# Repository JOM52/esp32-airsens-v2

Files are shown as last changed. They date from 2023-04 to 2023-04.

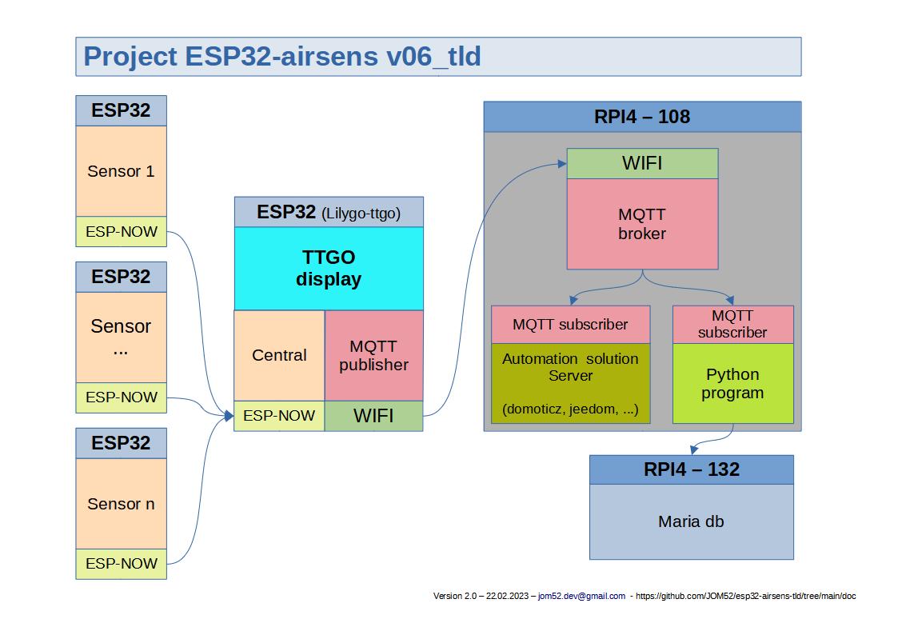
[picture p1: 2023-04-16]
doc/Schéma de principe.jpg

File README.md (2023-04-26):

# Projet : esp32-airsens 

Version 2

**esp32-airsens** est un projet de domotique qui consiste à créer des capteurs intelligents et connectés pour surveiller l'environnement. Ces capteurs sont basés sur le processeur ESP32 et le langage Micropython. Ils peuvent mesurer différents paramètres tels que la température, l'humidité, la pression atmosphérique et le niveau de charge de batterie. Ils envoient ensuite ces données à une centrale via un réseau sans fil. La centrale est un système Liligo TTGO qui reçoit les données des capteurs, les publie sur un broker MQTT et les affiche sur un écran. L'écran permet de visualiser les informations pertinentes pour chaque capteur.

La version 2 du projet introduit un nouveau concept pour la structure des données qui n'est pas compatible avec la version 1. Ce concept permet de simplifier la communication entre les capteurs et la centrale, ainsi que de gérer plus facilement les différents types de capteurs.

## Schéma de principe
https://github.com/JOM52/esp32-airsens-v2/blob/main/doc/Sch%C3%A9ma%20de%20principe.jpg

## Elément capteur:

La version 1.06_tld du hardware fonctionne bien et ne nécessite pas de modification.

Pour réduire la consommation d'énergie, cette version hard ne contient que l'essentiel pour faire fonctionner le capteur. La configuration se fait par une interface FTDI (USB to UART) qui se branche au besoin et les batteries se rechargent à part.

Dans l'exemple ci-après, le capteur est un BME 280 qui permet la mesure de la température, du taux d'humidité et de la pression atmosphérique.

https://github.com/JOM52/esp32-airsens-v2/blob/main/schema/Schema.pdf

On peut aussi utiliser des capteurs hdc1080 qui mesurent seulement la température et l'humidité relative.

### Hardware

Le hardware ESP32 est un microcontrôleur qui intègre des fonctionnalités de Wi-Fi et de Bluetooth, ainsi que des modules de gestion de l'alimentation, des filtres et des amplificateurs. Il peut se connecter à différents types de capteurs I2C, un protocole de communication série synchrone. 

### Software

Ce projet implémente les drivers pour les capteurs de type BME280, BME680 et HDV1080. Ces capteurs permettent de mesurer différentes grandeurs liées au climat ou à l'environnement. Dans la version 2 du projet, on peut choisir le type et le nombre de capteurs à utiliser dans le fichier de configuration. Toutefois, il faut tenir compte de l'impact sur la consommation d'énergie et la durée de vie de la batterie. Avec une batterie Li-Ion de 2Ah (type 18650), on peut, avec un seul capteur,  réaliser une mesure toutes les 5 minutes pendant environ un an.

#### Fichier de configuration du capteur

Le fichier de configuration permet de personnaliser le fonctionnement d'un capteur sans avoir à modifier le code source. Il contient des lignes de code en Micropython qui assignent des valeurs à des variables globales. Ces variables sont ensuite utilisées par le programme principal pour paramétrer les différents éléments du système. Le fichier de configuration n'a pas besoin d'une structure particulière, mais il peut être organisé en sections pour faciliter la lecture et la compréhension.

Le code ci-après permet de configurer un capteur connecté à un ESP32 qui utilise le protocole ESP-now pour envoyer des données à un proxy. Le capteur peut être de type hdc1080, bme280 ou bme680 et mesure la température, l'humidité, la pression, le gaz et l'altitude selon le cas. Le capteur est alimenté par une batterie et entre en mode deepsleep entre chaque acquisition pour économiser de l'énergie. La tension de la batterie est mesurée par un pont diviseur de tension. Le code utilise les constantes définies au début du fichier pour paramétrer les différents éléments du système. Par exemple, SENSOR_LOCATION indique le nom du capteur, T_DEEPSLEEP_MS indique la durée du mode deepsleep en millisecondes, SENSORS indique les types de capteurs disponibles et leurs mesures associées, ON_BATTERY indique si le capteur est alimenté par une batterie ou non, etc. Le code utilise également la variable PROXY_MAC_ADRESS pour indiquer l'adresse MAC du proxy auquel il envoie les données via 

Le code ci-dessous montre un exemple de fichier de configuration pour ce système:

```
# acquisitions
SENSOR_LOCATION = 'domo_2' 
T_DEEPSLEEP_MS = 300000

# sensor
SENSORS = {
    'hdc1080':['temp', 'hum'],
    'bme280':['temp', 'hum', 'pres'],
    'bme680':['temp', 'hum', 'pres', 'gas', 'alt']
    }
    
# power supply
ON_BATTERY = True
UBAT_100 = 4.2
UBAT_0 = 3.1

# I2C hardware config
BME_SDA_PIN = 21
BME_SCL_PIN = 22

# analog voltage measurement
R1 = 977000 # first divider bridge resistor
R2 = 312000 # second divider bridge resistor
DIV = R2 / (R1 + R2)  
ADC1_PIN = 35 # Measure of analog voltage (ex: battery voltage following)

#averaging of measurements
AVERAGING_BAT = 1
AVERAGING_BME = 1

# ESP-now
PROXY_MAC_ADRESS = b'<a\x05\rg\xcc'
# PROXY_MAC_ADRESS = b'<a\x05\x0c\xe7('
```

### Messages

Les valeurs mesurées pour chaque grandeur sont regroupées et transmises au broker MQTT dans un seul message. Le format de principe du message est le suivant:

`msg = (topic, location, grandeur 1, grandeur 2, .... , grandeur n, bat, rssi)`

Les grandeurs mesurées sont dépendantes des possibilités du capteur par exemple:

- HDC1080 : température, humidité
- BME280  : température, humidité, pression
- BME680  : température, humidité, pression, qualité de l'air

Les valeurs transmises à MQTT sont fonction de la configuration définie dans le fichier _conf du capteur.

#### Principe du logiciel capteur

Pour économiser l'énergie consommée, le capteur est placé en ***deepsleep*** entre chaque mesure. Le temps de sommeil est défini dans le fichier de configuration, en principe 5 minutes. Lors d'un éveil, le capteur lit le fichier de configuration, initialise les constantes, charge les librairies nécessaire, initialise le capteur, fait la mesure, mesure l'état de la batterie, transmets les valeurs à la centrale puis se met en ***deepsleep***

## Centrale

### Software

La centrale est le cœur du système de domotique. Elle a plusieurs fonctions :

- Elle reçoit et traite les messages valides envoyés par les capteurs sans fil.
- Elle adapte les messages au format de l'application de domotique choisie (domoticz, jeedom, ...).
- Elle transmet les valeurs de mesure à MQTT, un protocole de communication qui permet de diffuser les informations aux abonnés.
- Elle affiche différentes informations sur un écran couleur, comme les mesures et l'état des batteries des capteurs.

Les messages reçus ne sont pas confirmés au capteur. Cela signifie que si la centrale n'est pas disponible au moment où le capteur envoie un nouveau message, celui-ci est perdu. En principe cela ne pose pas de problème pour les mesures de grandeurs physiques qui varient peu dans le temps.

La centrale accepte tous les messages qui ont une structure correcte et qui proviennent d'un capteur dont elle connaît l'adresse MAC. Si le capteur est déjà enregistré dans le fichier de configuration et dans la mémoire programme, les nouvelles valeurs remplacent les anciennes. Sinon, le capteur est automatiquement reconnu et ajouté au fichier de configuration et à la mémoire programme.

La centrale dispose de deux boutons sur la version matérielle des Lilygo-ttgo qui permettent de sélectionner les différents affichages programmés. le choix se fait lorsque aucun bouton n'est pressé pendant 1 seconde.

Pour transmettre les mesures à MQTT, la centrale se connecte au réseau WIFI. Les valeurs de mesure sont formatées selon les besoins de l'application de domotique choisie puis envoyées au broker MQTT qui les publie aux abonnés.

### Fichier de configuration de la centrale

Le fichier de configuration est un fichier standard Micropython. 

```
#!/usr/bin/env python3
# -*- coding: utf-8 -*-
"""
file: airsens_central_v2.py 
author: jom52
email: jom52.dev@gmail.com
github: https://github.com/JOM52/esp32-airsens-v2

v0.4.0 : 05.02.2023 --> first prototype
v0.4.1 : 05.03.2023 --> small changes Venezia
v2.0.0 : 11.04.2023 --> adapté pour la version 2
"""
from ubinascii import hexlify
from machine import unique_id

#SYSTEM
WAIT_TIME_ON_RESET = 300 # seconds to wait before the machine reset in case of error

# MQTT
BROKER_IP = '192.168.1.108'
TOPIC = 'airsens_domoticz'
BROKER_CLIENT_ID = hexlify(unique_id())

# TTGO
BUTTON_MODE_PIN = 35
BUTTON_PAGE_PIN = 0
DEFAULT_MODE = 0 # Mode auto
DEFAULT_ROW_ON_SCREEN = 5 # given by the display hardware and the font size
CHOICE_TIMER_MS = 1000 # milli seconds
REFRESH_SCREEN_TIMER_MS = 10000 # mode auto: display next location each ... milli seconds
BUTTON_DEBOUNCE_TIMER_MS = 10 # milli seconds

# WIFI
WIFI_WAN = 'jmb-home'
WIFI_PW = 'lu-mba01'

# BATTERY
BAT_MAX = 4.2 # 100%
BAT_MIN = 3.2 # 0%
BAT_OK = 3.4 # si ubat plus grand -> ok
BAT_LOW = 3.3 # si ubat plus petit -> alarm
BAT_PENTE = (100-0)/(BAT_MAX-BAT_MIN)
BAT_OFFSET = 100 - BAT_PENTE * BAT_MAX
print('% = ' + str(BAT_PENTE) + ' + ' + str(BAT_OFFSET))
```

#### Code de la centrale évolution

*Dans une prochaine version il est prévu de modifier le programme pour:*

- *introduire un processus d'identification et d'enregistrement des capteurs par la centrale. Ainsi seuls des capteurs reconnus, validés et enregistrés seront autorisés à transmettre des mesures à la centrale.*
- *de crypter les message pour empêcher que les messages soient lus par des entités non autorisées.*

### Hardware

La centrale utilise un circuit Lilygo-ttgo qui comprend le processeur, une interface USB, un affichage de 135x240 pixels et deux boutons. Dans la version actuelle, ce circuit est utilisé tel quel. Les boutons sont utilisés comme suit:

- bouton 1 --> next **Mode**

- bouton 2 --> next **Page**

  le choix se fait lorsque aucun bouton n'est pressé pendant 1 seconde

### Connection réseau attribution des canaux

Désactivez l'attribution automatique des canaux sur votre routeur Wi-Fi : si le routeur Wi-Fi de votre réseau Wi-Fi est configuré pour attribuer automatiquement le canal Wi-Fi, il peut changer le canal du réseau s'il détecte des interférences provenant d'autres routeurs Wi-Fi. Lorsque cela se produit, les appareils ESP connectés au réseau Wi-Fi changeront également de canal pour correspondre au routeur, mais les autres appareils ESPNow uniquement resteront sur le canal précédent et la communication sera perdue. Pour atténuer cela, configurez votre routeur Wi-Fi pour qu'il utilise un canal Wi-Fi fixe ou configurez vos appareils pour analyser à nouveau les canaux Wi-Fi s'ils ne parviennent pas à trouver leurs homologues attendus sur le canal actuel.

Il faut configurer le sensor pour utiliser le même canal (channel) que le router wifi

## MQTT mosquitto

Le logiciel MQTT fonctionne comme un éditeur (broker). Il est à l'écoute des auteur (publishers) qui publient des données et les diffuse auprès des abonnés (subscribers).

MQTT est installé comme un service sur un Raspberry PI. Il reçoit les informations transmises par les auteurs qui publient les données (les capteurs) et les rediffuse vers tous les abonnés sans aucun contrôle de validité. Son rôle se limite à faire transiter les données depuis les auteurs vers les abonnés. La responsabilité de la validation et du contrôle des données est laissé à la centrale.

Pour recevoir les données depuis le broker il suffit souscrire au broker sur le TOPIC concerné.

*description de l'installation et de la configuration de MQTT à placer ici* 

## Programme python airsens_mqtt

C'est un programme Python qui s'abonne à des topics MQTT pour les capteurs dont les données doivent être enregistrées dans une base de données. Ce programme est installé comme un service sur le raspberry PI. 

Il consulte le fichier de configuration de la centrale pour connaitre les mac-adress des capteurs reconnus par la centrale.

Il reçoit les données depuis MQTT, vérifie que le capteur est reconnu et, si oui, les enregistre dans la base de données airsens sur MariaDB (anciennement MySql) sur le Raspberry PI .

Ce programme se charge également d'alarmer l'utilisateur (par un mail, un WhatsApp ou autre) lorsque l'accumulateur d'un capteur doit être rechargé. 

*description de l'installation d'un service sur RPI à placer ici*

## Programme de domotique

Les mesures des capteurs peuvent être transmises à un logiciel de domotique (domoticz, jeedom, ...) pour être représentés graphiquement ou intervenir dans différentes alarmes. 

La gestion des messages à destination des logiciels de domotique se font pour chaque logiciel  (domoticz, jeedom, ...) dans une classe spécifique.

Pour Domoticz, le format des messages est le suivant:

 {  "**command**": "udevice",  "**idx**" : 7,  "**nvalue**" : 0,  "**svalue**" : "90;2975.00", "**parse**": false } avec:

- **command**: udevice pour un capteur
- **idx**: index du capteur dans domoticz
- **nvalue**: sans importance pour un capteur
- **svalue**: valeurs mesurées p.ex. température; humidité; pression, ...

plus de détails: https://piandmore.wordpress.com/2019/02/04/mqtt-out-for-domoticz/

## Corrections à apporter

- [ ] **Identification unique des capteurs**
  - [ ] Compléter le topic par le type de capteur et un id unique pour pouvoir assurer de différentier chaque capteur donc 
    le TOPIC sera constitué comme suit: SENSOR_LOCATION / SENSOR_TYPE / SENSOR_ID 
  - [ ] Adapter le programme airsens_v2_jeedom.py
  - [ ] Adapter la table airsens_v2 dans la base de données airsens sur le RPI 139 
- [ ] **Perte de connexion en cas de coupure réseau**
  - [ ] En cas de coupure réseau, le central se perd et ne redémarre pas automatiquement. 
- [ ] **Sensor**
  - [ ] Analyser si la possibilité d'avoir plusieurs sensors sur un seul capteur à du sens et si non supprimer le code correspondant
  - [ ] Prévoir de désactiver les messages pour le suivi si le sensor est sur batterie (ON_BATTERY = False)
- [ ] **Central**
  - [ ] Analyser pourquoi le programme se plante et ne redémarre pas en cas de coupure réseau 
- [ ] **Capteur**
  - [ ] Modifier la valeur du condensateur (C3) (10uF ?) pour que le reset se fasse à l'enclenchement du sensor
  - [ ] Etudier si l'implémentation du FTDI sur le capteur à du sens ou s'il rester avec un FTDI externe

Ce thème fera objet d'un futur projet.

## GITHUB

Ce projet est maintenu dans GitHub, avec une licence GPL. Il est accessible par le lien 
https://github.com/JOM52/esp32-airsens-v2

Pravidondaz avril 2023

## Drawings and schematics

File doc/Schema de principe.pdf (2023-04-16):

# ESP32 RPI4 – 108

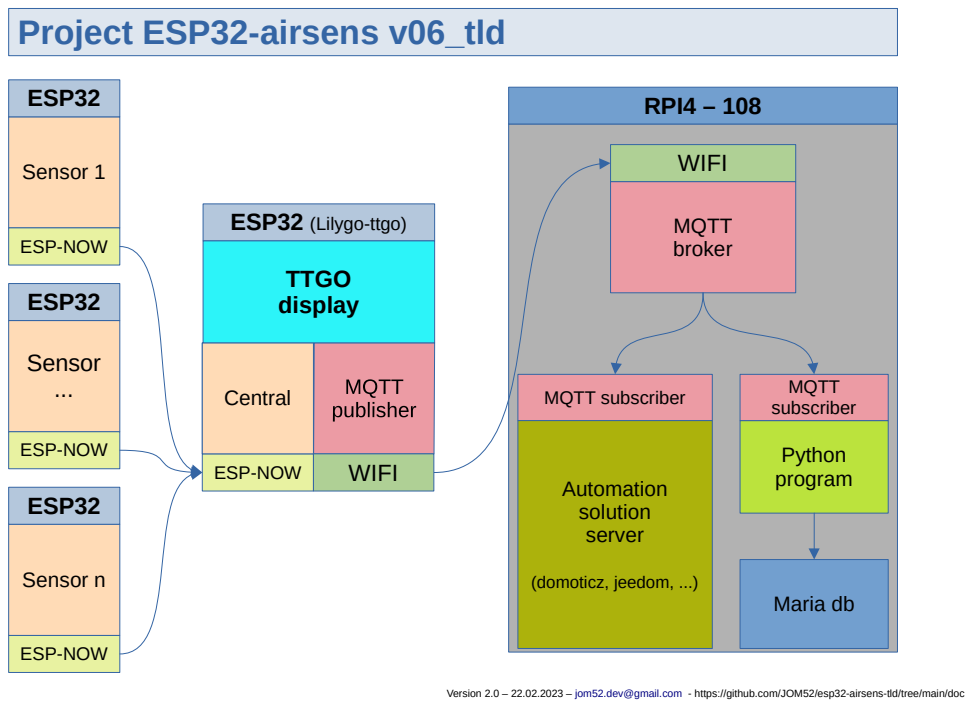
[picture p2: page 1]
Sensor 1; ESP-NOW; Sensor ...; ESP32; Sensor n; ESP32 (Lilygo-ttgo); MQTT broker; MQTT subscriber; Python program; Maria db; WIFI; Automation solution server; (domoticz, jeedom, ...); Project ESP32-airsens v06_tld; MQTT subscriber Central; TTGO display

Central

ESP-NOW | WIFI

Version 2.0 – 22.02.2023 – jom52.dev@gmail.com - https://github.com/JOM52/esp32-airsens-tld/tree/main/doc

# ESP32

# RPI4 – 108

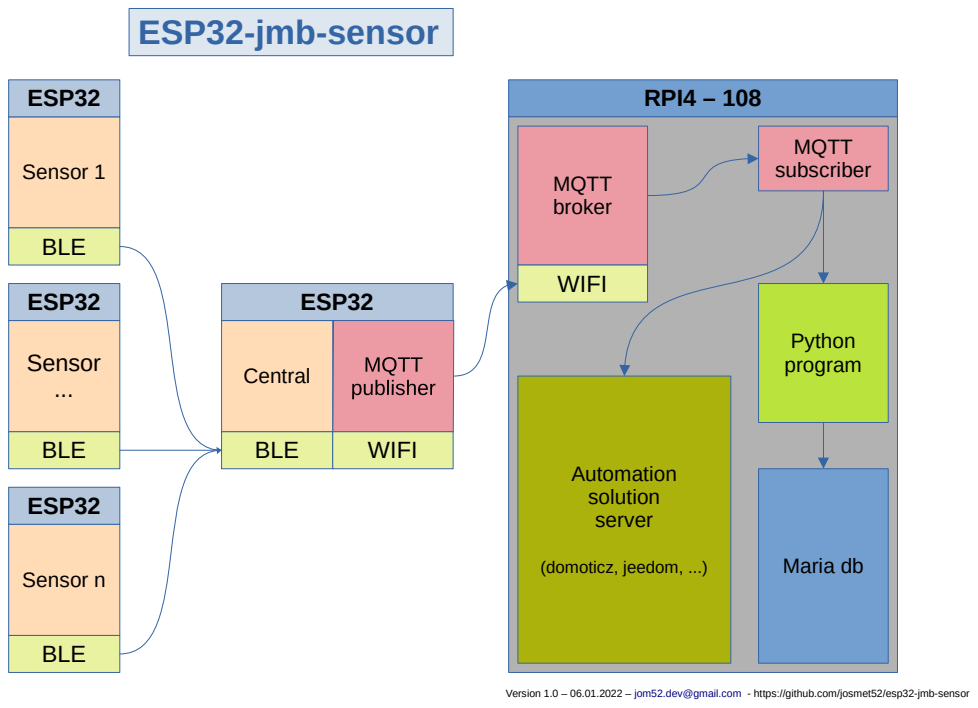
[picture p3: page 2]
Sensor 1; BLE; Sensor ...; ESP32; Sensor n; Central; MQTT broker; MQTT subscriber; Python program; Maria db; WIFI; Automation solution server; (domoticz, jeedom, ...); ESP32-jmb-sensor

Version 1.0 – 06.01.2022 – jom52.dev@gmail.com - https://github.com/josmet52/esp32-jmb-sensor

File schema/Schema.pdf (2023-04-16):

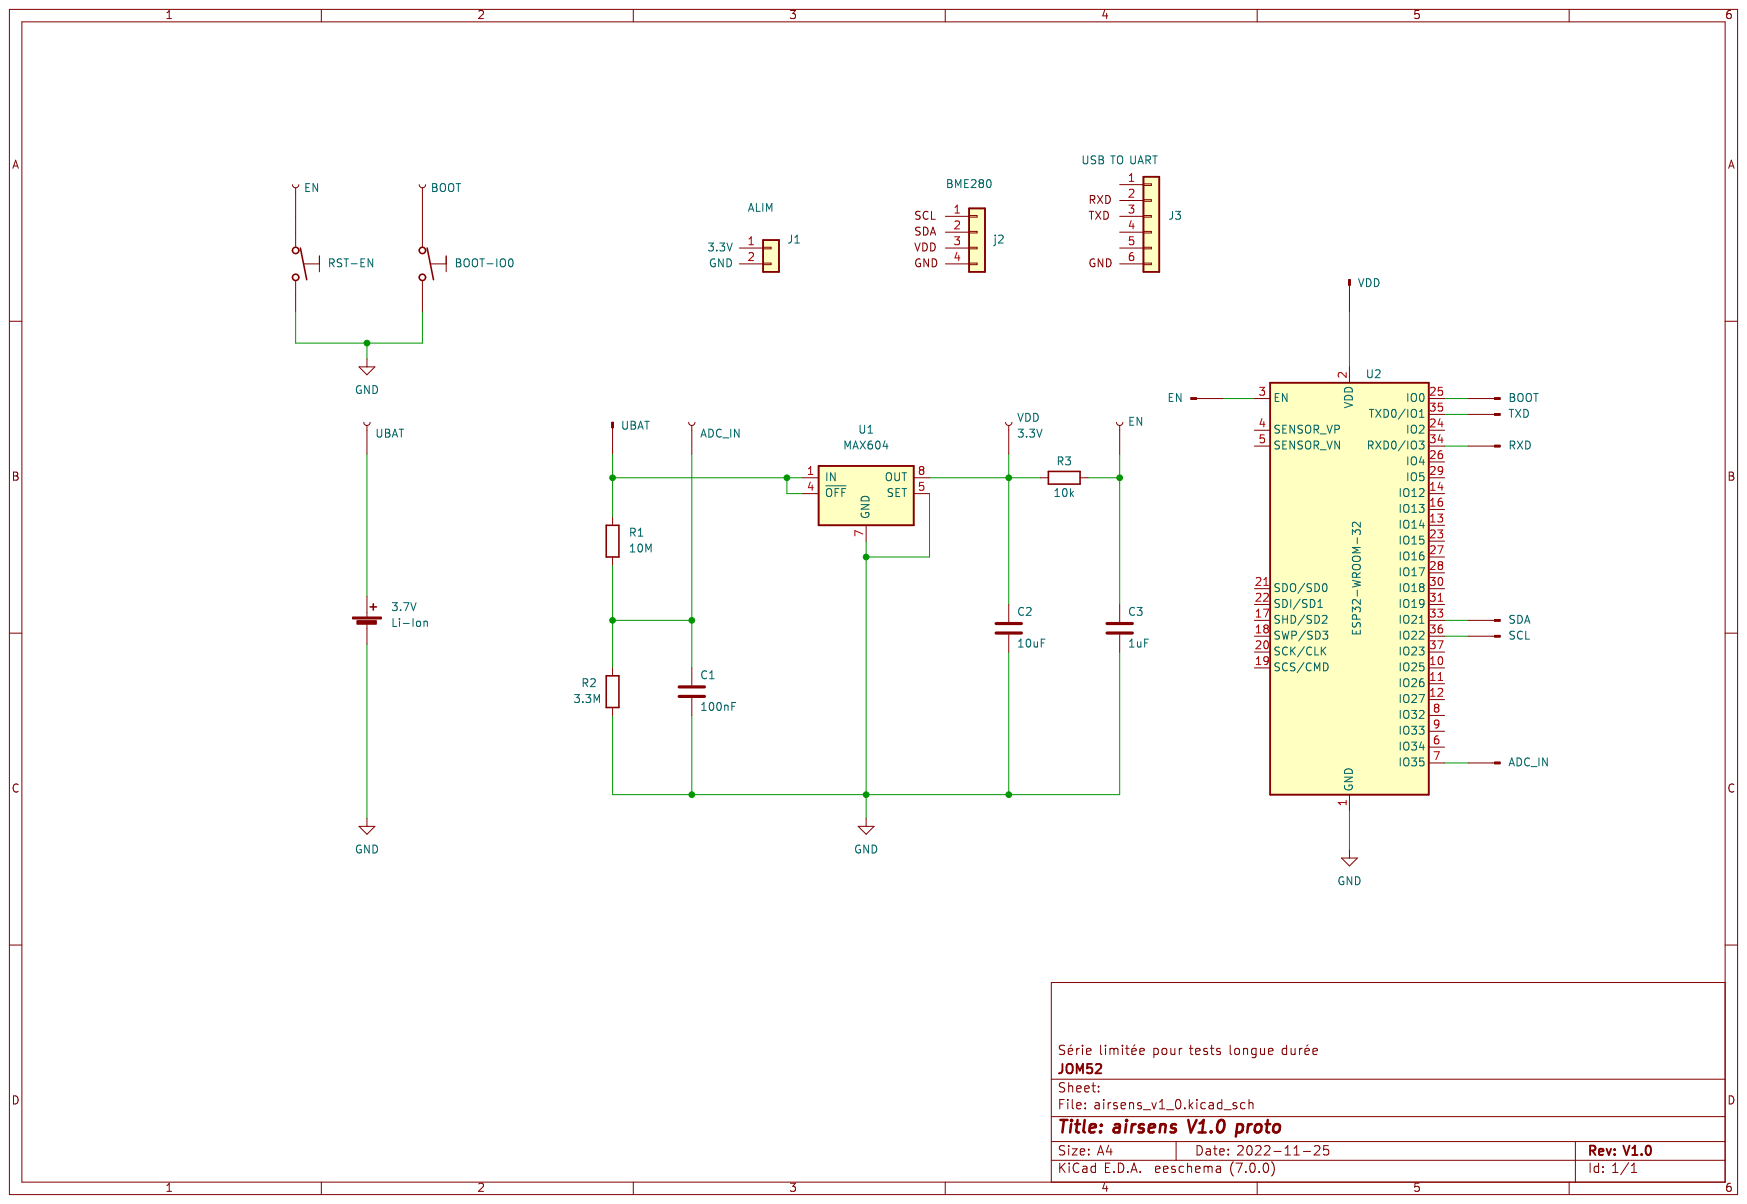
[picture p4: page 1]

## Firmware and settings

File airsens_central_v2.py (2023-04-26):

#!/usr/bin/env python3
# -*- coding: utf-8 -*-

"""
file: airsens_central.py 

author: jom52
email: jom52.dev@gmail.com
github: https://github.com/JOM52/esp32-airsens-v2

v0.4.0 : 05.02.2023 --> first prototype
v0.4.1 : 26.02.2023 --> optimisation du fichier conf
v0.4.2 : 27.02.2023 --> amelioration de la boucle Main
v0.4.3 : 28.02.2023 --> grand nettoyage
v0.4.4 : 01.03.2022 --> button_1_action simplified
v0.4.5 : 05.03.2023 --> small changes Venezia
v1.0.0 : 11.03.2023 --> first production version
v1.1.0 : 07.04.2023 --> adaptation for domoticz process begin
-----------------------------------------------------------------------
v2.0.0 : 10.04.2023 --> new data structure no more compatible with old versions
v2.0.1 : 21.04.2023 --> small cosmetic changes
v2.0.2 : 21.04.2023 --> added menu ABOUT and modified WLAN MAC adresse format
v2.0.3 : 26.04.2023 --> small cosmetics changes
"""
VERSION = '2.0.3'
PROGRAM_NAME = 'airsens_central_v2.py'
PROGRAM_NAME_SHORT = 'airsens'
print('Loading "' + PROGRAM_NAME + '" v' + VERSION + ' please be patient ...')
import airsens_central_conf_v2 as conf

from ubinascii import hexlify, unhexlify
from machine import Pin, Timer, reset
from espnow import ESPNow
from utime import sleep_ms, localtime, time, gmtime
from network import WLAN, STA_IF, AP_IF, WIFI_PS_NONE
from ntptime import settime
from math import ceil

from lib.log_and_count import LogAndCount
from lib.ttgo_display import TtgoTdisplay
from lib.umqttsimple import MQTTClient


class GlobalVar:
    data_pointer = None
    current_page = None
    current_mode = None
    wlan_mac = None
    sta = None
    


class Show:

    def __init__(self,
                 ttgo_display, # classes
                 datas, data_time  # lists to store the datas
                 ):
        self.ttgo_display = ttgo_display
        self.datas = datas
        self.data_time = data_time
        self.refresh_screen_timer = Timer(0)  # timer to switch to the next ecran
        self.refresh_screen_timer.init(period=conf.REFRESH_SCREEN_TIMER_MS, mode=Timer.PERIODIC,
                                       callback=self.refresh_screen_from_timer)

    # called by the timer because he give a not usefull param
    # and the procedure refresh_screen don't use it
    def refresh_screen_from_timer(self, z):
        self.refresh_screen()

    # refresh the screen for any mode
    def refresh_screen(self):
            
        self.ttgo_display.cls()
        if GlobalVar.current_mode == 0: # mode auto
            GlobalVar.data_pointer = self.manage_data_pointer(GlobalVar.data_pointer, len(self.datas))
            self.display_auto(self.datas, GlobalVar.data_pointer)
            
        elif GlobalVar.current_mode == 1: # mode overview
            self.display_overview(title='OVERVIEW ', n_row=4, n_col=1, data_list=self.datas,
                                       current_page=GlobalVar.current_page, current_mode=GlobalVar.current_mode)
        elif GlobalVar.current_mode == 2: # mode battery status
            self.display_overview(title='BATTERY ', n_row=4, n_col=1, data_list=self.datas,
                                       current_page=GlobalVar.current_page, current_mode=GlobalVar.current_mode)
        elif GlobalVar.current_mode == 3: # mode About
            if GlobalVar.current_page == 0:
                self.ttgo_display.write_line(0, PROGRAM_NAME_SHORT + ' v' + VERSION + '  p1/2', color=self.ttgo_display.COLOR_WHITE)  
                self.ttgo_display.write_about_line(1,'MAC:', str(hexlify(GlobalVar.wlan_mac, ':').decode().upper()))
                self.ttgo_display.write_about_line(2,'WIFI channel:', str(GlobalVar.sta.config("channel")))
                self.ttgo_display.write_about_line(3,'WAN:', conf.WIFI_WAN)
                self.ttgo_display.write_about_line(4,'Central IP:', str(GlobalVar.sta.ifconfig()[0]))
            elif GlobalVar.current_page == 1:
                self.ttgo_display.write_line(0, PROGRAM_NAME_SHORT + ' v' + VERSION + '  p2/2', color=self.ttgo_display.COLOR_WHITE)  
                self.ttgo_display.write_about_line(1,'MQTT topic:', '')
                self.ttgo_display.write_about_line(2,'   ', conf.TOPIC)
                self.ttgo_display.write_about_line(3,'MQTT broker IP:', '')
                self.ttgo_display.write_about_line(4,'   ', conf.BROKER_IP)
            else:
                self.ttgo_display.write_line(1, 'No datas', color=self.ttgo_display.COLOR_RED)


    # display the data for the modes auto
    def display_auto(self, datas, data_pointer):
        if datas:
            location, temp_f, hum_f, pres_f, bat_val, bat_f, bat_pc_f, bat_color = datas[data_pointer]
            self.ttgo_display.write_line(0, location, color=self.ttgo_display.COLOR_WHITE)
            self.ttgo_display.write_line(1, 'Temp = ' + str(temp_f) + '"C', color=self.ttgo_display.COLOR_CYAN)
            self.ttgo_display.write_line(2, 'Hum  = ' + str(hum_f) + '%', color=self.ttgo_display.COLOR_CYAN)
            if float(pres_f) > 0:
                self.ttgo_display.write_line(3, 'Pres = ' + str(pres_f) + 'hPa', color=self.ttgo_display.COLOR_CYAN)
            self.ttgo_display.write_line(4, 'Batt = ' + str(bat_f) + 'V ' + str(bat_pc_f) + '%', color=bat_color)
        else:
            self.ttgo_display.write_line(1, 'No datas', color=self.ttgo_display.COLOR_RED)
            

    def display_overview(self, title, n_row, n_col, data_list, current_page, current_mode):
        self.ttgo_display.cls()
        if data_list:
            len_data_list = len(data_list)
            self.ttgo_display.write_line(0, title + ' p '
                                         + str(current_page+1) + '/'
                                         + '{:.0f}'.format(ceil(len_data_list/n_row)),
                                         color=self.ttgo_display.COLOR_WHITE)
            for i in range(0, len(data_list)):
                if (current_page * n_row) <= i < ((current_page + 1) * n_row):
                    row = i - current_page * n_row + 1
                    location, temp_f, hum_f, pres_f, bat_val, bat_f, bat_pc_f, bat_color = data_list[i]
                    if current_mode == 1:
                        self.ttgo_display.write_line_overview(row, location, str(temp_f) + 'C', str(hum_f) + '%',
                                                              txt_color=self.ttgo_display.COLOR_CYAN,
                                                              val_color=self.ttgo_display.COLOR_YELLOW)
                    elif current_mode == 2:
                        self.ttgo_display.write_line_bat(row, location, str(bat_f) + 'V', str(bat_pc_f) + '%',
                                                         txt_color=self.ttgo_display.COLOR_CYAN, bat_color=bat_color)
        else:
            self.ttgo_display.write_line(1, 'No datas', color=self.ttgo_display.COLOR_RED)
            
    def manage_data_pointer(self, pointer, len_data_list):
        if pointer < len_data_list - 1:
            pointer += 1
        else:
            pointer = 0
        return pointer


class Menu:

    def __init__(self,
                 show, ttgo_display, # classes
                 datas, data_time  # lists to store the datas
                 ):
        self.interrupt_pin = None
        self.show = show
        self.ttgo_display = ttgo_display
        self.choice_ok_timer = Timer(1)  # timer to valid the mode choice
        self.button_debounce_timer = Timer(2)  # timer to debounce the switches
        self.datas = datas
        self.data_time = data_time

    # callback procedure for any button pressed
    # execute the action corresponding to the pressed button
    def on_button_pressed(self, z):
        if self.interrupt_pin == Pin(conf.BUTTON_MODE_PIN):
            self.button_1_action()
        elif self.interrupt_pin == Pin(conf.BUTTON_PAGE_PIN):
            self.button_2_action()

    # debounce any button pressed 
    def button_debounce(self, pin):
        self.interrupt_pin = pin
        self.button_debounce_timer.init(mode=Timer.ONE_SHOT,
                                        period=conf.BUTTON_DEBOUNCE_TIMER_MS, callback=self.on_button_pressed)

    # execute actions selected by the button 1 (executed from the timer choice_ok_timer)
    def choice_ok(self, z):
        # after any change in the modes reinit the refresh timer
        self.show.refresh_screen_timer.deinit()
        if GlobalVar.current_mode == 0:
            'mode auto'
            GlobalVar.data_pointer = -1
        elif GlobalVar.current_mode == 1 or GlobalVar.current_mode == 2:
            'mode overview'
            GlobalVar.current_page = 0
        elif GlobalVar.current_mode == 3:
            GlobalVar.current_page = 0
            pass
           
        self.show.refresh_screen_timer.init(period=conf.REFRESH_SCREEN_TIMER_MS, mode=Timer.PERIODIC,
                                       callback=self.show.refresh_screen_from_timer)
        self.show.refresh_screen()

    def button_1_action(self):
        MODES = ['AUTO', 'OVERVIEW', 'BATTERY', 'ABOUT'] # modes
        self.choice_ok_timer.deinit()
        self.ttgo_display.cls()
        # increment ttgo_curent_mode and reset if too big
        len_modes = len(MODES) # store the length of the list
        GlobalVar.current_mode = (GlobalVar.current_mode + 1) % len_modes # use modulo to wrap around
        # display the menu with the active line in yellow
        # use a list comprehension to create a list of colors based on the current mode
        colors = [self.ttgo_display.COLOR_YELLOW if i == GlobalVar.current_mode else self.ttgo_display.COLOR_CYAN for i in range(len_modes)]
        # loop over the modes and colors and write each line
        for i, (mode, color) in enumerate(zip(MODES, colors)):
            self.ttgo_display.write_line(i, mode, color=color)
        # init timer to do action of the select menu entry
        self.choice_ok_timer.init(mode=Timer.ONE_SHOT, period=conf.CHOICE_TIMER_MS, callback=self.choice_ok)
        # change the current mode

    # change the current page
    def button_2_action(self):
        self.show.refresh_screen_timer.deinit()
        if GlobalVar.current_mode == 0:
            # mode auto
            pass
        elif GlobalVar.current_mode == 1 or GlobalVar.current_mode == 2:
            # mode overview
            current_page_inc = 1
            len_liste = 4
            GlobalVar.current_page = self.get_next_page(self.datas, len_liste, GlobalVar.current_page, current_page_inc)
        elif GlobalVar.current_mode == 3:
            # mode About
            GlobalVar.current_page = (GlobalVar.current_page + 1) % 2
            pass
           
        self.show.refresh_screen_timer.init(period=conf.REFRESH_SCREEN_TIMER_MS, mode=Timer.PERIODIC,
                                       callback=self.show.refresh_screen_from_timer)
        self.show.refresh_screen()

    def get_next_page(self, datas, len_liste, current_page, current_page_inc):
        
        # Calculer le nombre total de pages à afficher
        n_pages = len(datas) // len_liste
        if len(datas) % len_liste > 0:
            n_pages += 1
        # Augmenter ou diminuer la page courante selon l'incrément
        # Si la page courante dépasse le nombre total de pages, revenir à la première page
        current_page = (current_page + current_page_inc) % n_pages
        return current_page


class Central:

    def __init__(self):
        self.log = LogAndCount()
        self.ttgo_display = TtgoTdisplay()
        self.ttgo_display.cls()

        GlobalVar.current_mode = conf.DEFAULT_MODE  # default state
        GlobalVar.current_page = 0
        GlobalVar.data_pointer = -1  # start value

        # initialisation listes
        self.datas = []
        self.data_time = []

        # instantiation classes
        self.show = Show(self.ttgo_display, self.datas, self.data_time)
        self.menu = Menu(self.show, self.ttgo_display, self.datas, self.data_time)
        
        # instantiation ESPNow
        self.espnow = ESPNow()
        self.espnow.active(True)
    
    def get_formated_time(self, time=None):
        if time is None:
            dt = localtime()
        else:
            dt = localtime(int(time))
        year = '{:04d}'.format(dt[0])
        month = '{:02d}'.format(dt[1])
        day = '{:02d}'.format(dt[2])
        hour = '{:02d}'.format(dt[3])
        minute = '{:02d}'.format(dt[4])
        second = '{:02d}'.format(dt[5])
        return day + '.' + month + '.' + year + ' ' + hour + ':' + minute + ':' + second

    def wifi_reset(self):  # Reset Wi-FI to AP_IF off, STA_IF on and disconnected
        sta = WLAN(STA_IF)
        sta.active(False)
        ap = WLAN(AP_IF)
        ap.active(False)
        sta.active(True)
        return sta, ap
    
    def mqtt_connect_and_subscribe(self):
        try:
            client = MQTTClient(conf.BROKER_CLIENT_ID, conf.BROKER_IP)
            client.connect(True)
            return client
        except Exception as err:
            self.log.log_error('MQTT_connect_and_subscribe', self.log.error_detail(err), to_print=True)
            self.reset_esp32()
            
    def add_new_measurement(self, new_data):
        location_exist = False
        for i, d in enumerate(self.datas):
            if d[0] == new_data[0]:
                self.datas[i] = new_data
                self.data_time[i] = time()
                location_exist = True
                break
        # append new location
        if not location_exist:
            self.datas.append(new_data)
            self.data_time.append(time())


    def reset_esp32(self):
        wait_time = conf.WAIT_TIME_ON_RESET
        while wait_time > 0:
            print('rebooting ESP32 in ' + str(wait_time) + 's')
            sleep_ms(1000)
            wait_time -= 1
        reset()

            

    def main(self):
        try:
            self.ttgo_display.cls()
            self.ttgo_display.write_centred_line(0, '... Initialazing ...', color=self.ttgo_display.COLOR_CYAN)
            self.ttgo_display.write_centred_line(2, PROGRAM_NAME, color=self.ttgo_display.COLOR_YELLOW)
            self.ttgo_display.write_centred_line(3, 'Version:' + VERSION, color=self.ttgo_display.COLOR_YELLOW)
            sta, ap = self.wifi_reset()  # Reset Wi-FI to AP off, STA on and disconnected
            sta.config(ps_mode=WIFI_PS_NONE) # ..then disable power saving
            GlobalVar.wlan_mac = sta.config('mac')
            GlobalVar.sta = sta
            sta.connect(conf.WIFI_WAN, conf.WIFI_PW)
            while not sta.isconnected():
                sleep_ms(200)
            txt = " ".join(["WLAN STA:",  str(hexlify(sta.config('mac'), ':').decode().upper()), 'channel:', str(sta.config("channel"))])
            print('---------------------------------------------------------------------------------------------------------------------')
            print(PROGRAM_NAME + ' v' + VERSION)
            print(self.get_formated_time())
            print("Central MAC Address:", hexlify(GlobalVar.wlan_mac, ':').decode().upper()) # Show MAC for peering
            print(txt)
            print('Central IP:', sta.ifconfig()[0])
            print('Central WLAN:', conf.WIFI_WAN)
            print('MQTT broker IP: ' + conf.BROKER_IP + ' topic: ' + conf.TOPIC)
            print("Main running on channel:", sta.config('channel'))
            print('ESPNow active:', self.espnow)
            print('---------------------------------------------------------------------------------------------------------------------')
            # Setup the button input pin with a pull-up resistor.
            button_mode = Pin(conf.BUTTON_MODE_PIN, Pin.IN, Pin.PULL_UP)
            button_ecran = Pin(conf.BUTTON_PAGE_PIN, Pin.IN, Pin.PULL_UP)
            # Register an interrupt on rising button input.
            button_ecran.irq(self.menu.button_debounce, Pin.IRQ_RISING)
            button_mode.irq(self.menu.button_debounce, Pin.IRQ_RISING)
            for peer, msg in self.espnow:
                if peer and msg:
                    if len(msg.decode('utf-8').strip()) > 0:
                        '''New message received'''
#                         print('new message received', msg)
                        jmb_id, location, sensor_type, rx_measurements = msg.decode('utf-8').split(',')
                        rx_measurements = rx_measurements.split(';')
                        # format the numbers for the small display
                        mes_list = []
                        mes_dict = {}
                        # structure of dictionary
                        # mes_dict['grandeur'] = [value, format for print, format for small ttgo display]
                        mes_dict['temp'] = [0, '{:.2f}', '{:.1f}']
                        mes_dict['hum'] = [0, '{:.0f}', '{:.0f}']
                        mes_dict['pres'] = [0, '{:.0f}', '{:.0f}']
                        mes_dict['gas'] = [0, '{:.0f}', '{:.0f}']
                        mes_dict['alt'] = [0, '{:.0f}', '{:.0f}']
                        mes_dict['bat'] = [0, '{:.2f}', '{:.2f}']
                        # pour chaque grandeur dans rx_measurment
                        for rx_mes in rx_measurements:
                            # separe grandeur and value [0] pour grandeur, [1] pour valeur
                            rx_mes = rx_mes.split(':')
                            # read the mes_dict value for this grandeur
                            dict_record = mes_dict[rx_mes[0]]
                            # set the new value for this record
                            dict_record[0] = float(rx_mes[1])
                            # update the mes_dict 
                            mes_dict[rx_mes[0]] = dict_record
                            
                            # append this grandeur to the list of measurements
                            mes_list.append(rx_mes[0])
                        # append the bat, bat_f, bat_pc, bat_pc_f tp the list of measurements
                        bat = float(mes_dict['bat'][0])
                        bat_f = '{:.2f}'.format(bat)
                        bat_pc = min(((bat * conf.BAT_PENTE) + conf.BAT_OFFSET), 100)  
                        bat_pc_f = '{:.0f}'.format(bat_pc)
                        
                        # change the color for the battery to indicate the charge state
                        if float(bat) < conf.BAT_LOW:
                            color_bat = self.ttgo_display.COLOR_RED
                        elif conf.BAT_LOW <= float(bat) <= conf.BAT_OK:
                            color_bat = self.ttgo_display.COLOR_ORANGE
                        elif float(bat) > conf.BAT_OK:
                            color_bat = self.ttgo_display.COLOR_GREEN
                        else:
                            color_bat = self.ttgo_display.COLOR_WHITE
                        
                        # prepare the list of éléments for adding a new measurement
                        new_measurement_list = [
                            sensor_type,
                            mes_dict['temp'][2].format(mes_dict['temp'][0]),
                            mes_dict['hum'][2].format(mes_dict['hum'][0]),
                            mes_dict['pres'][2].format(mes_dict['pres'][0]),
                            mes_dict['bat'][2].format(mes_dict['bat'][0]),
                            bat_f, bat_pc_f, color_bat
                            ]
                        self.add_new_measurement(new_measurement_list)
                        
                        # check if connected to Wi-FI and if not reconnect 
                        if not sta.isconnected():
                            sta, ap = self.wifi_reset()  # Reset Wi-FI to AP off, STA on and disconnected
                            sta.connect(conf.WIFI_WAN, conf.WIFI_PW)
                            while not sta.isconnected():
                                sleep_ms(200)
                            self.log.log_error('WIFI connection lost, reconnecting', to_print = True)
                            sta.config(ps_mode=WIFI_PS_NONE)  # ..then disable power saving

                        # has the message the right identificator
                        if jmb_id == 'jmb':
                            passe = self.log.counters('passe', True)
                            try:
                                # create the list of data  to send
                                txt_mes = [conf.TOPIC, location]
                                # append the values in the list
                                mes = []
                                for act_mes in mes_list:
                                    mes.append(mes_dict[act_mes][0])
                                txt_mes.append(str(mes).replace(',',':'))
                                # add the rssi to the list
                                txt_mes.append(str(sta.status('rssi')))
#                                 print(txt_mes)
                                # create the message
                                msg = ','.join(txt_mes)
                                # send the message to MQTT
                                client = self.mqtt_connect_and_subscribe()  # conf.BROKER_CLIENT_ID, conf.BROKER_IP, conf.TOPIC)
                                if client is not None:
                                    client.publish(conf.TOPIC, msg)
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
